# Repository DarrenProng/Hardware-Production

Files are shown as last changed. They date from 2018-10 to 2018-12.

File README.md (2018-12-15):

# TEA5767 FM Radio Receiver Module
## Created by: Darren Prong at Humber College Technical Laboratories
## CENG 317 Instructor: Kristian Medri

## Table of Contents
1. [Introduction](#introduction)

2. [Specifications](#specifications)

3. [Design Files](#design-files)

4. [Assembly](#assembly)

5. [Test Code](#test-code)

### Introduction
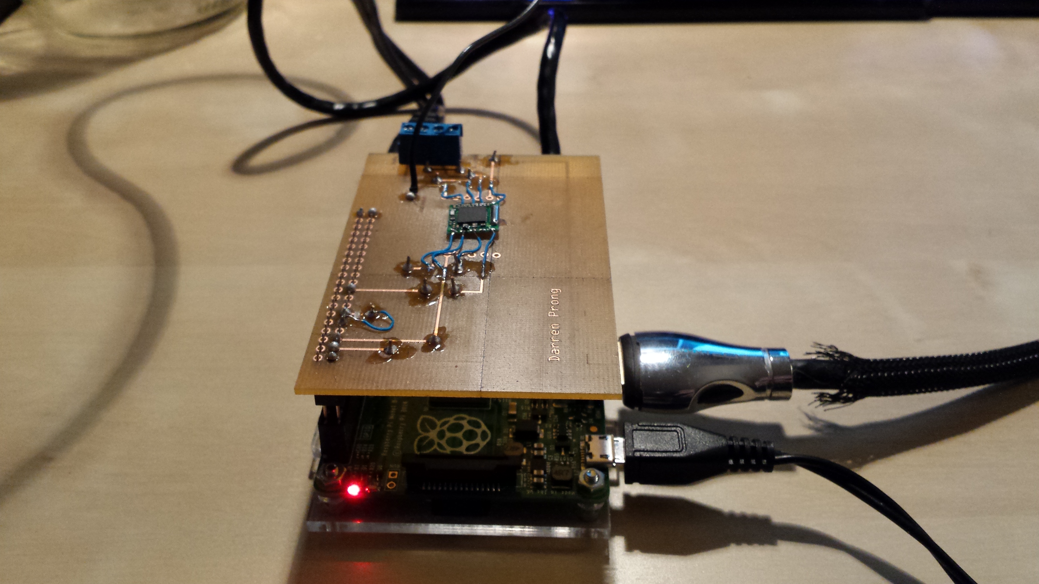
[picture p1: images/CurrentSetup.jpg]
Image of Prototype


This list will allow you to complete a working FM Radio Receiver using the Raspberry PI 3b+ in conjunction with a TEA5767 I2C device.

Ill start by listing the required components, where to buy them, how to design then assemble those components, then finalize with testing the device in an appropriate enviroment.

This project was completed over a 15-week semester, however with these steps, a working prototype could be completed in a week from purchasing components to hearing music on the receiver.

### Specifications
Heres a list of all parts needed to complete this project.

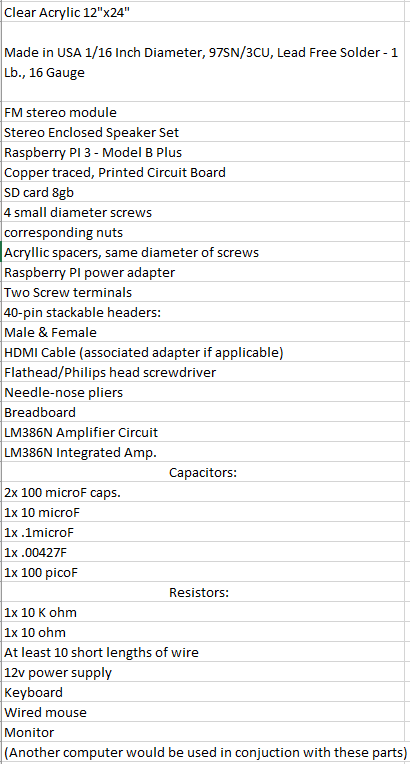
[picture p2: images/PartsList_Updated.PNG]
Image of Parts


Youre budget will vary from mine, as I had a number of components and tools and access to a prototyping lab which greatly decreased my overhead costs. 
I also had to buy additional components that were not originally on the budget or parts list files that I have uploaded HERE on my repository.
As well, my major mistake of frying a Raspberry PI (which could set you back another $50.00) wasn't included in the budget.
The amplifier originally was planned to be the Class-D amp supplied by buyapi.ca, however I had to put togther the LM386 due to time contraints. However, looking back, this would be a better option; thats why I left it on the final parts list.
My total budget by the end of the project was $122.68CAD.
I had intitially proposed a $108 total budget.

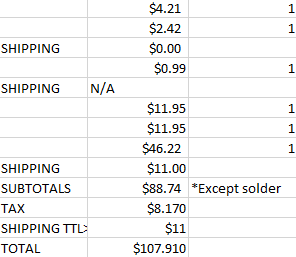
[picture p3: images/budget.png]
Image of Budget


Here is the updated budget
These are the costs to be expected, at least at a minimum.
This was the first attempt at wrangling up some of these cheap sensors.
I went for the cheapest option, and they never arrived.

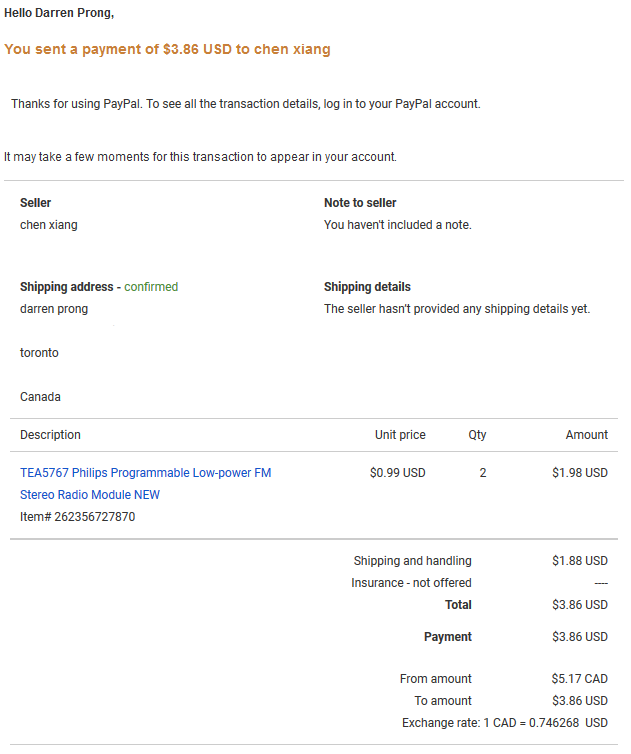
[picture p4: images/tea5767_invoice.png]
Image of Invoice1


Therefore, go for the one that works, and is quick. I bought the back up at oddwires.com for $15.25 USD:

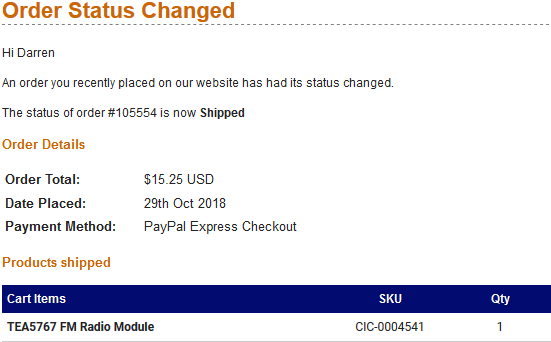
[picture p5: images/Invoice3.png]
Image of Invoice3


The Pi 3B+ is also my choice for which version to go with. 

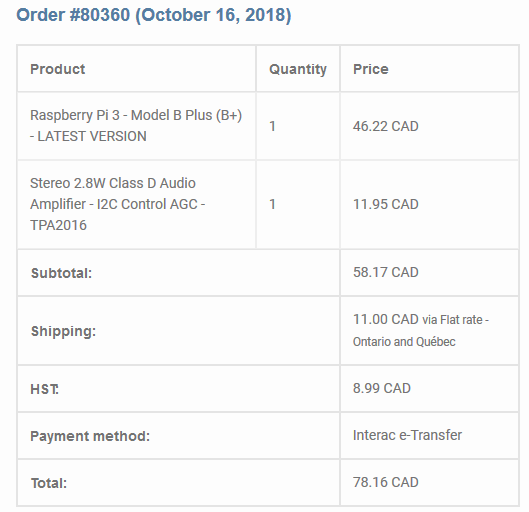
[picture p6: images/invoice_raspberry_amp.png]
Image of Invoice2


Its the same price as the other Pi's but if you already have the associated pieces for assembly, no need to order a whole parts
kit.

Again, these prices are location dependent, as your geographical situation could greatly increase shipping costs or parts availablity. 
As well, in our prototyping lab, we have access to a $20,000 laser cutter, a lot of spare components and tools, the expertise of professionals, and a great deal more time.

### Design Files
Designing this next two major parts will require some trial and error if you haven't used these programs before. Also, if you've ordered your parts and awaiting the sensor in the mail, this can be done in the interim.
To design the device PCB I used the freeware "Fritzing" (which is in BETA at the time of this publication.) 

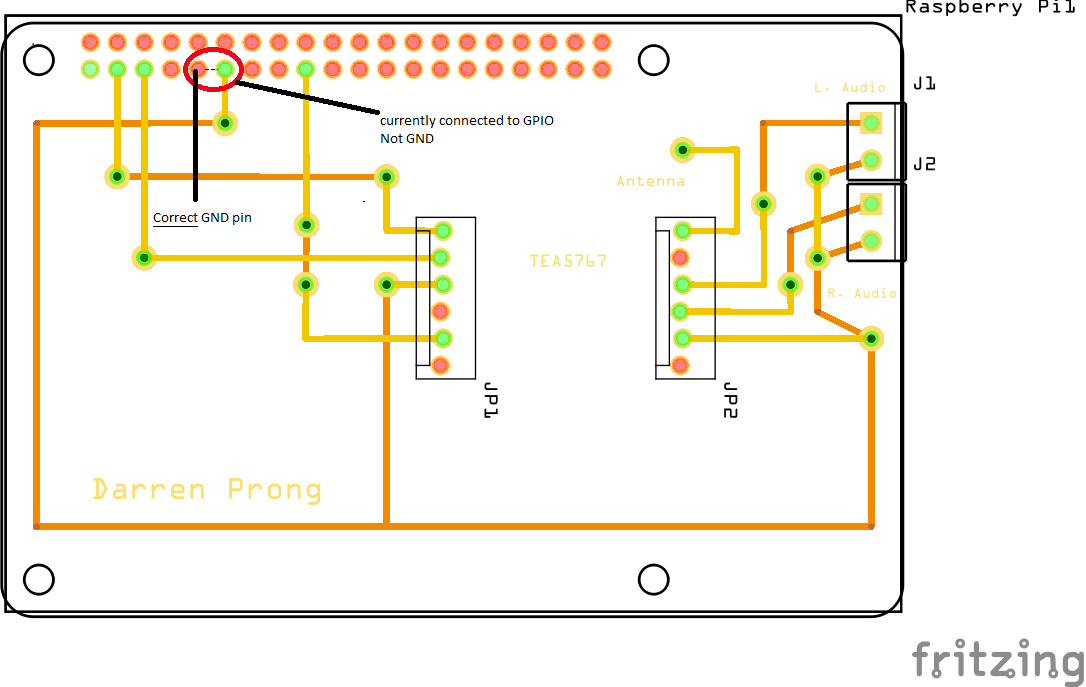
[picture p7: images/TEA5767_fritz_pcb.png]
Image of Fritzing


This files could still use some tweaking, and maybe some personal customization; however, this is the simplest design I could create and good for a beginner to learn the basics.

And for the enclosure, CorelDRAW was used on a free 15-day trial as well as access to the program in our lab.
The enclosure on CorelDRAW:

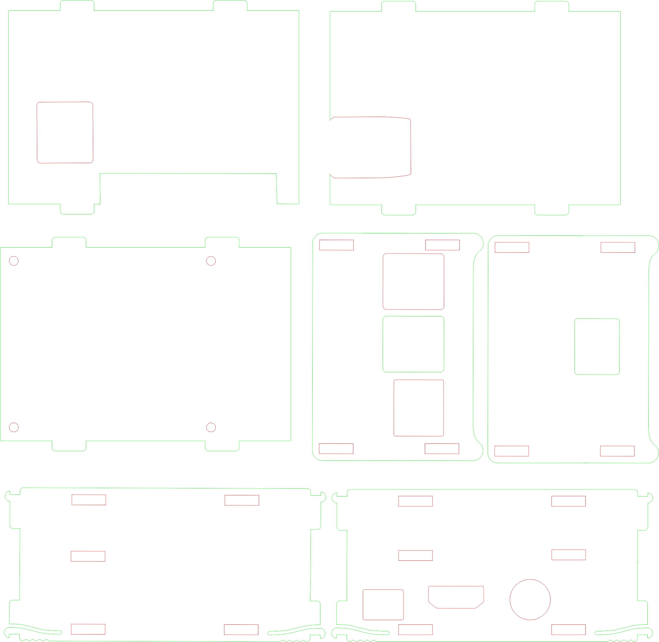
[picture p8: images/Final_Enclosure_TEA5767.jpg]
Image of Enclosure


After these are designed, you can send the fritzing file away to be printed.
The enclosure was printed a few times, with minor changes for each new job. Its still not a perfect fit, but the file you have here [Enclosure](https://raw.githubusercontent.com/DarrenProng/Hardware-Production/master/Final_Enclosure_TEA5767.cdr) will work but the fit is tight, and the middle plate is under pressure from the USB ports pressing from underneath causing it to bend slightly. 

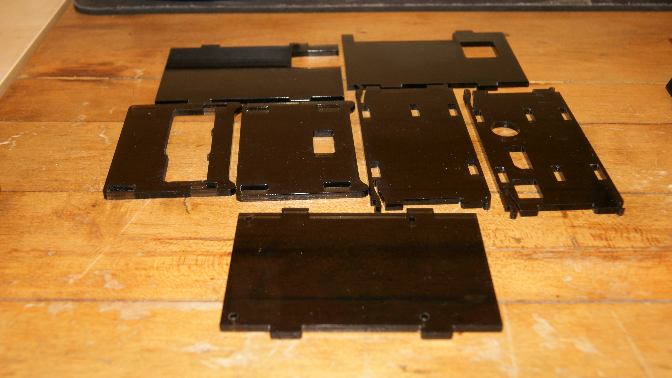
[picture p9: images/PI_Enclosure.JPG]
Image of Pieces

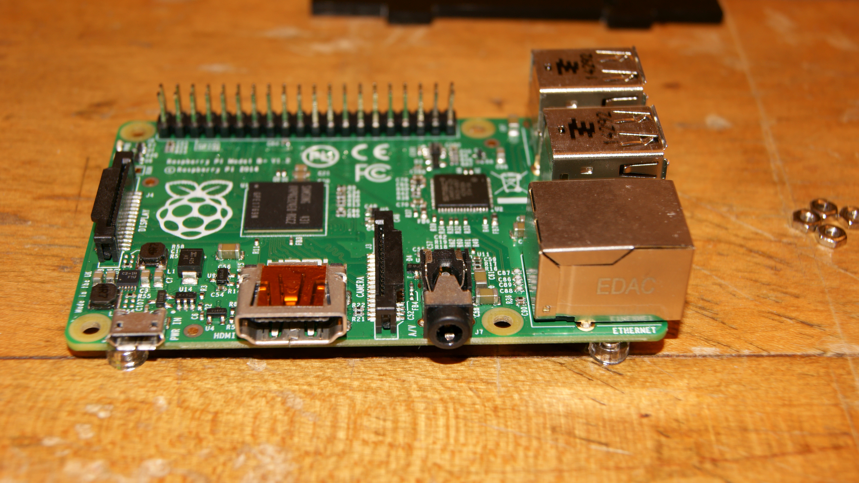
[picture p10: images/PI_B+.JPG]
Image of BarePi

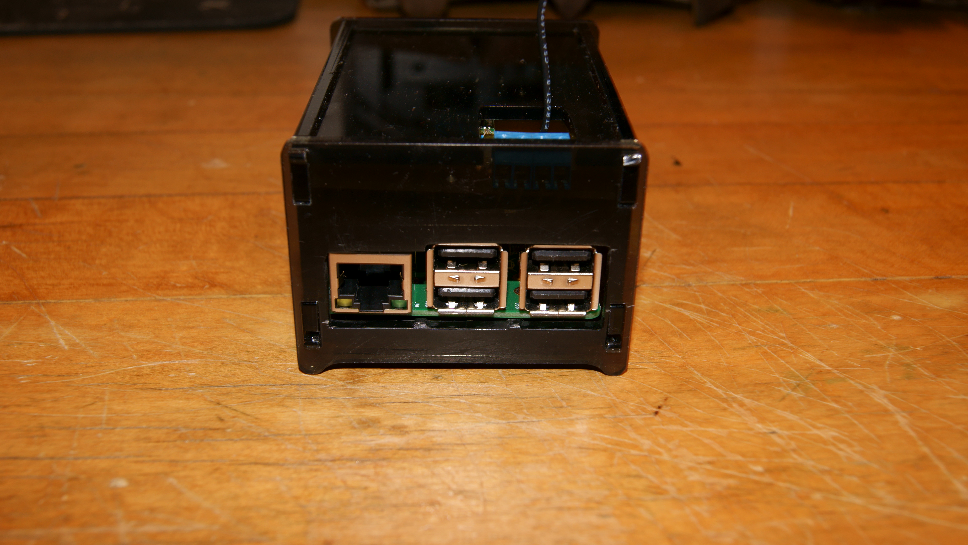
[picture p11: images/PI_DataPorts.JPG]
Image of PiPorts

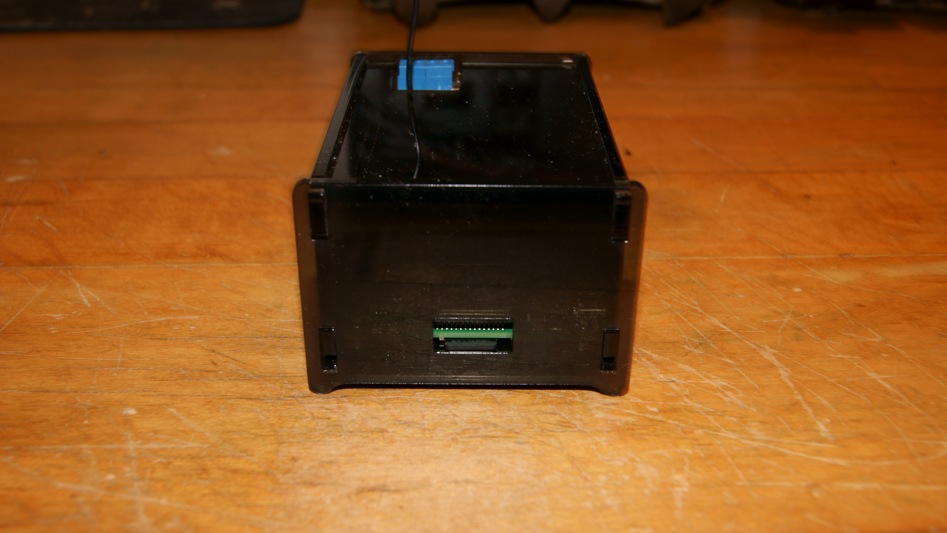
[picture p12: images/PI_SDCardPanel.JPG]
Image of PI_SDCardPanel


I had to remove the I/O spacing bars, and file down the cutouts for my design, however the design .cdr file included in 
this repository, won't have this missalignment.

### Assembly
Once the parts are in hand, the design files printed and assembled, Heres what you should have in hand:
...

Start by attaching the the sensor to the PCB, I used hotglue.

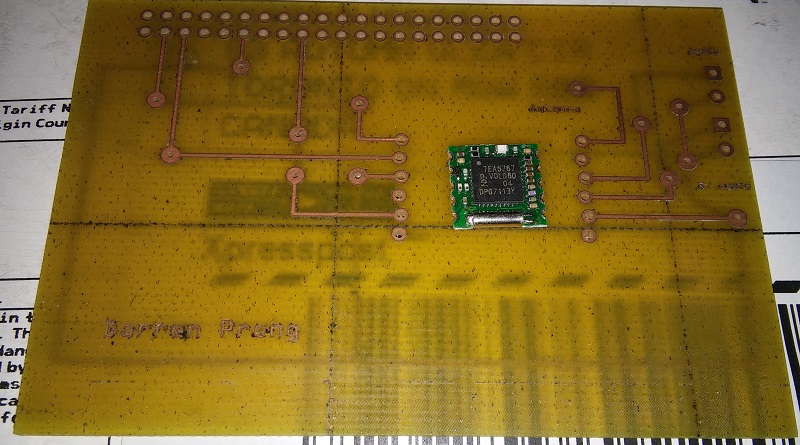
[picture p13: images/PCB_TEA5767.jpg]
Image of TEA5767


Next step will be to solder a jumper wire from each terminal on the sensor to the corresponding trace on the PCB.

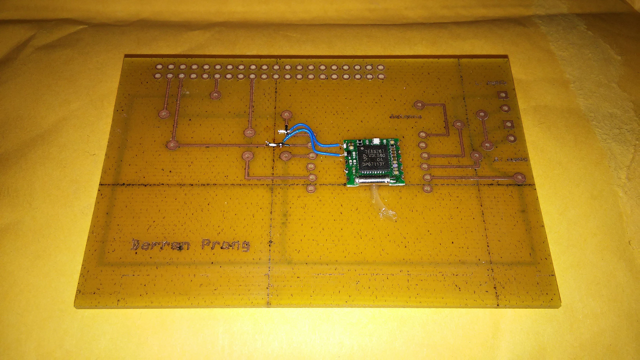
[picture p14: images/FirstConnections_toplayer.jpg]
Image of Connection


Next will be to solder the via's. I recommend that you take a small amount of 20gauge wire(1cm in length) strip only one end and then insert into all the via's. This will hold it inside the via briefly while you solder the flip side. Solder the entire side with exposed wire first, then flip, remove the insulation, and solder that side for each via.

Double check the shape of each via and how the solder "flows" from the wire onto the copper pad. This ensures a solid connection. It should appear like a sloping hill, or a "Hershey Kiss".

Next, the 40-pin stackable header, along with the two screw terminals to be used with your speakers.

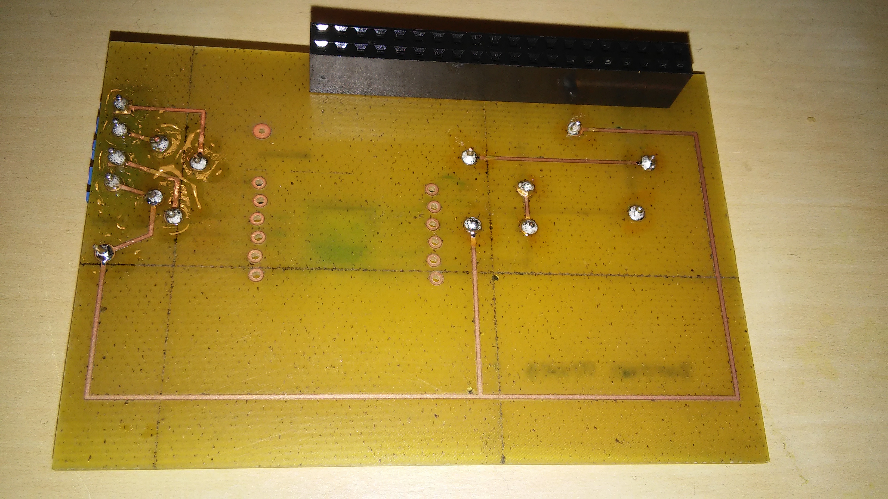
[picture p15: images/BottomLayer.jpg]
Image of Bottom


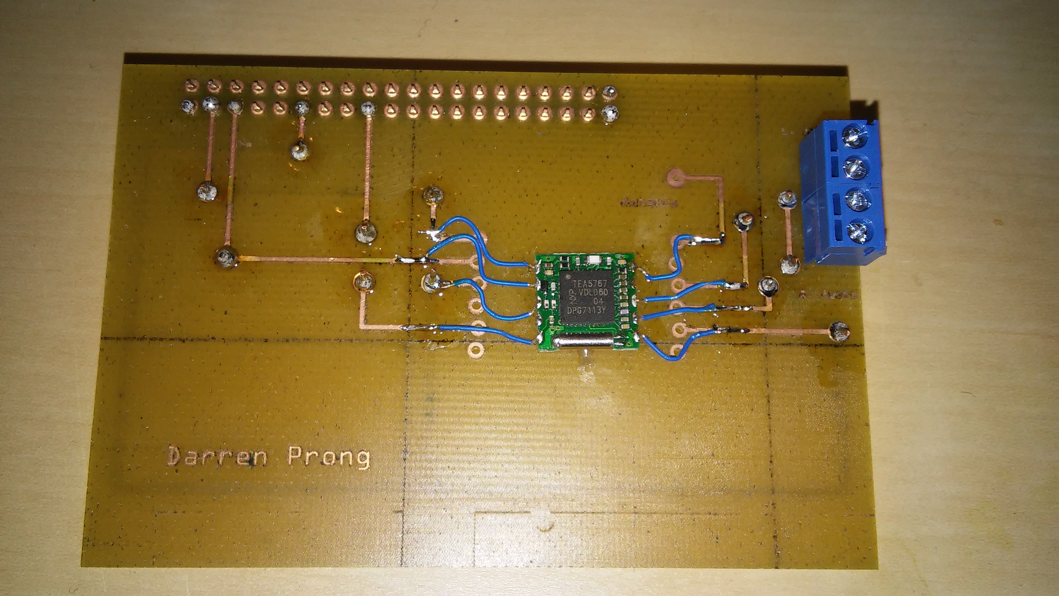
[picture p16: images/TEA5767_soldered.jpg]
Image of Top


Soldering all 40pins isn't necessary, I only soldered the pins I was using, and two on the far end of the header.

I also left my male 40-pin header plugged in, so I didnt lose it. However, you'll notice it doesn't rest flush up agaisnt the the female header. This could potentially damage both headers as well as the device. 

Best practice would be to disconnect from the PI each time your completed testing. 

You can now solder on a length of wire (up to you how long) to act as the antenna. Solder this in a similar way as you did with the via's.

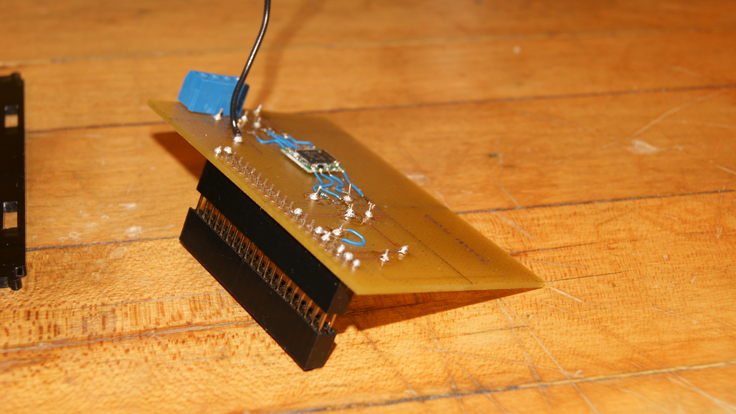
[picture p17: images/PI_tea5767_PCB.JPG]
Image of PI


PS. Ignore the jumper wire from the ground trace to pin 5. This was where I made a critical error in my fritzing design.
The updated .fzz has fixed this issue.

 Next and final step for assembly, attach your PI to the base plate of the acryllic enclosure with the ordered hardware and printed standoffs. 
 
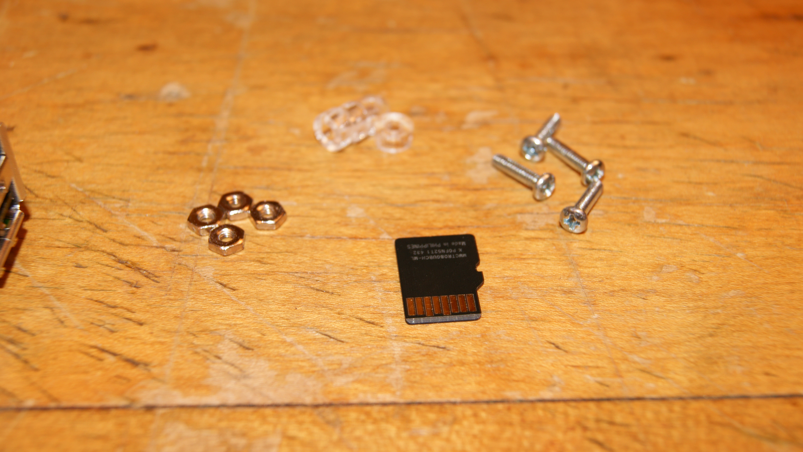
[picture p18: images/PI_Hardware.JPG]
Image of Hardware
 
 
 Do one hole at a time. Keep the device firmly planted on a flat surface. (hang over on hole on the edge of a table for example) place the standoffs in between the board and the base plate. Line up the holes, and insert a screw. While keeping the screw in place with your small philips head screw driver, place a nut on the threads with the needle nose pliers. The pliers are to be help still, just keep the nut from turning. Use the screwdriver to tighten, just until enough threads are engaged to hold the screw in place. Repeat for all four holes. Final step is to tighten down snugly, not firmly, on all four screws.
 
You can now attach all parts of the enclosure to the base, and plug in the PCB/device combo into the GPIO pins.

The final product:

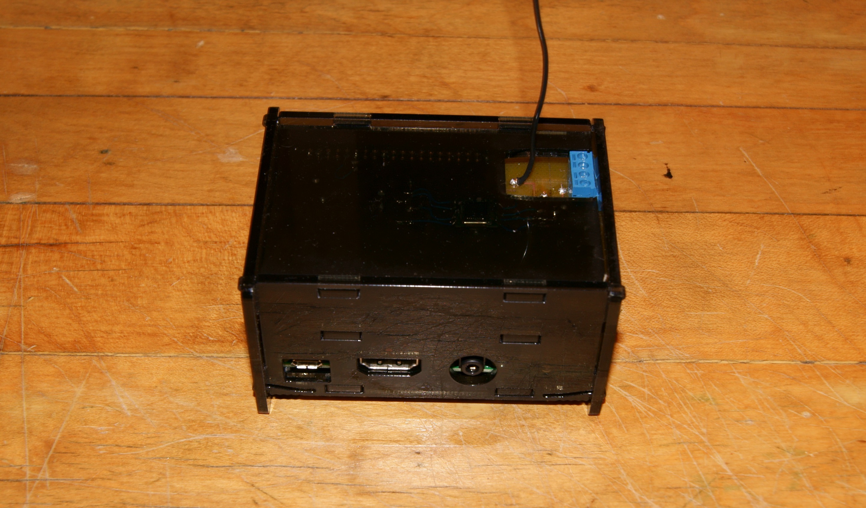
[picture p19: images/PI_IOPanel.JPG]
Image of Case


### Test Code

The first step in making sure your PI will be able to play music will be its ability to first boot up, then to enable I2C devices, then to detect that the PI can recognize the sensor.

First, enable the I2C bus on your PI.

Go to:
/boot/config.txt

add these lines to the bottom of the file:
```
dtparam=i2c_arm=on
dtparam=spi=on
dtparam=i2s=on
dtparam=i2c1=on
```

Next, type:	
```
gpio -v
```
	
 Make sure you have WiringPi libraries installed
	If no version is available, please try the following commands: 	

 ```
sudo apt-get install upgrade
sudo apt-get install update
sudo apt-get install i2c-tools
sudo apt-get install wiringpi
sudo apt-get install smbus
```
Now we need to edit the file
```
sudo nano /etc/modules
```

Add these lines here: 

```
i2c-bcm2708
```

and here:

```
i2c-dev

```

at the bottom of the file, and remember to write to file before exiting.

Also, we need to enable i2c at boot. So now we run the:

```
sudo raspi-config
```
Next, navigate through the first menu 

<!-- answer from: anonymoose March 9th 2017 Source. https://raspberrypi.stackexchange.com/questions/63076/advanced-options-i2c-not-showing -->

found this at raspberrypi.stackexchange.com//questions/63076/advanced-options-i2c-not-showing. This shows step by step what to do in a 12 second .gif.

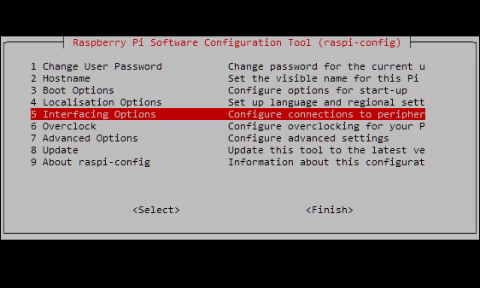
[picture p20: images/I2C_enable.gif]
Image of EnableConfig


After the I2C bus has been enabled, the /modules file edited and saved, any missing libraries installed;
open a new file for editing in VIM. Name the file radio.c. 
```
radio.c

#include <wiringPi.h>

#include <wiringPiI2C.h>

#include <stdio.h>

#include <stdlib.h>

int main( int argc, char *argv[]) {

  printf ("RPi - tea5767 Philips FM Tuner v0.3 \n") ;

  unsigned char radio[5] = {0};

  int fd;

  int dID = 0x60; // i2c Channel the device is on

  unsigned char frequencyH = 0;

  unsigned char frequencyL = 0;

  unsigned int frequencyB;

  double frequency = strtod(argv[1],NULL);

  frequencyB=4*(frequency*1000000+225000)/32768; //calculating PLL word

  frequencyH=frequencyB>>8;

  frequencyL=frequencyB&0XFF;

  printf ("Frequency = "); printf("%f",frequency);

  printf("\n"); // data to be sent

  radio[0]=frequencyH; //FREQUENCY H

  radio[1]=frequencyL; //FREQUENCY L

  radio[2]=0xB0; //3 byte (0xB0): high side LO injection is on,.

  radio[3]=0x10; //4 byte (0x10) : Xtal is 32.768 kHz

  radio[4]=0x00; //5 byte0x00)

 if((fd=wiringPiI2CSetup(dID))<0){

 printf("error opening i2c channel\n\r");

 }

write (fd, (unsigned int)radio, 5) ;

return 0;

}
```
Once saved as radio.c, 

```
gcc -o radio radio.c -lwiringPi
```

Credit for the above code goes to "halfluck" on the Raspberry Pi forums.
```
https://www.raspberrypi.org/forums/viewtopic.php?t=53680&p=419429

```

The command to be run here is: 
```
sudo i2cdetect -y 1
```

This will display all open addresses and will display a hexadecimal value representing the module. We need 0x60. 

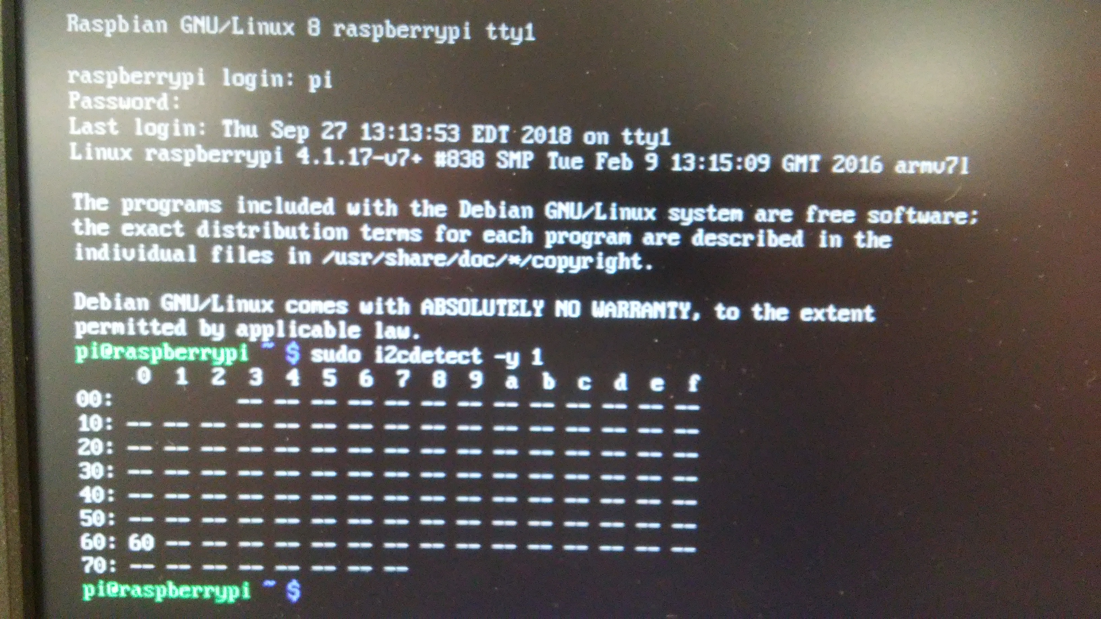
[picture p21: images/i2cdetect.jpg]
Image of Detecting


If you see any other address, there may be some other issue regarding your device; I would look into this guide:

https://raspberrypi.stackexchange.com/questions/76072/inconsistent-i2c-bus-address-listings-causing-sensor-reading-issues

or many others like it across the web. 

If everything is looking good, you can continue.
Now we're ready to play music but most likely you haven't plugged in your speakers. I had two 4.3ohm desktop speakers
from an old set I found at my house. One was broken and couldn't play anything, and the other was working just fine.
Test them first in your amplifier. Supply a low power frequency to the input of the LM386, shown here:

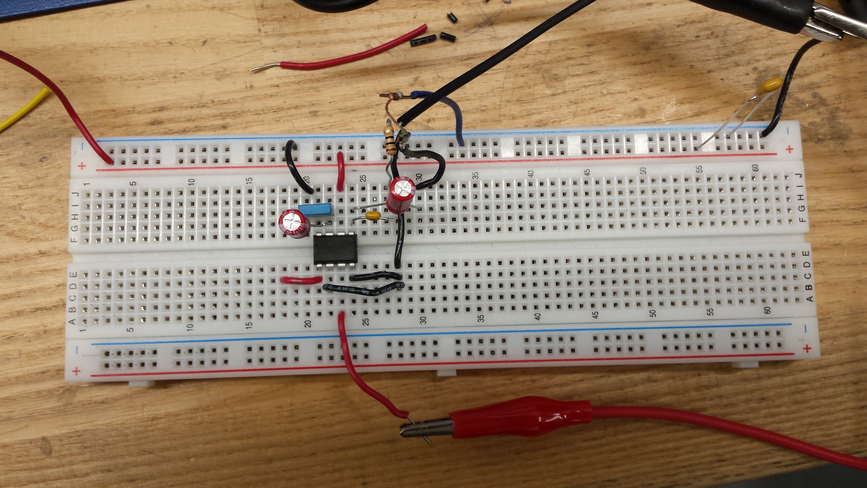
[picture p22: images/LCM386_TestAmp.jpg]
Image of Amplifier


Heres it breadboarded virtually using fritzing:

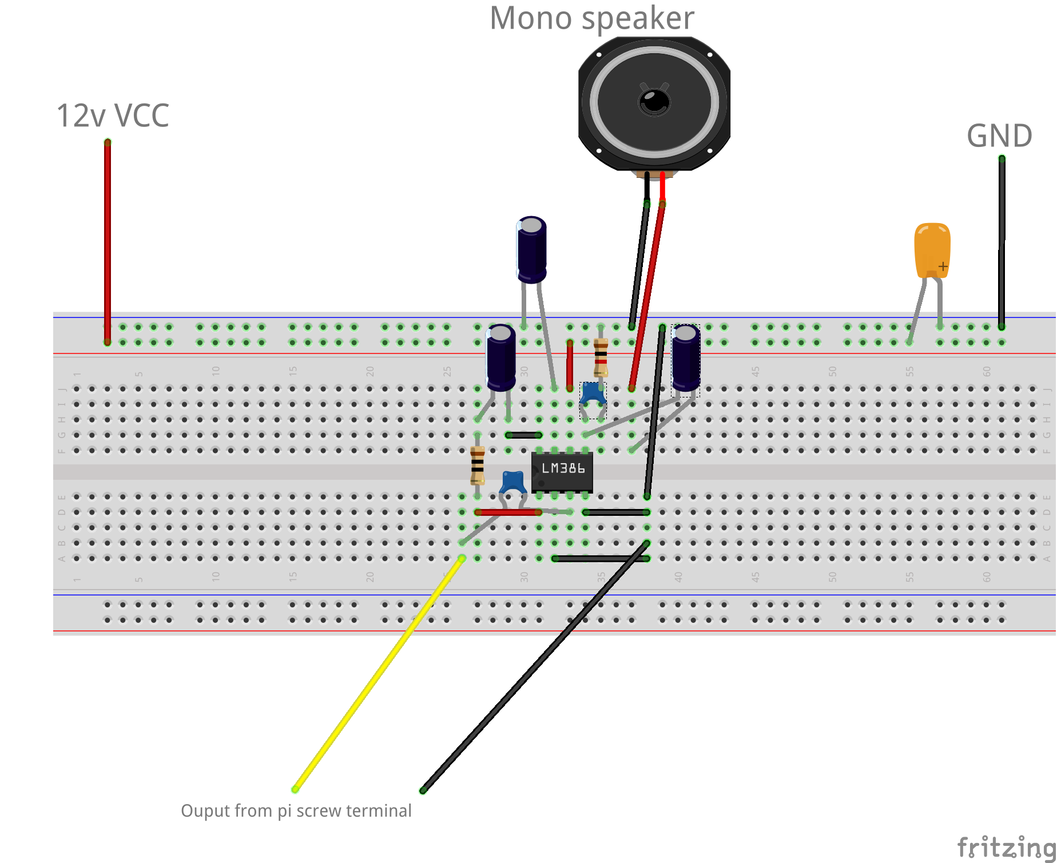
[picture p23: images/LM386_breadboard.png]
Image of Amplifier


Once you test has gone through with your speaker, test it out while running the PI hooked up to the amp.
```
sudo ./radio xx.x //your radio station frequency of choice
```
It should come out sounding a little something like this:

https://www.youtube.com/embed/gSB8UnMIgSc

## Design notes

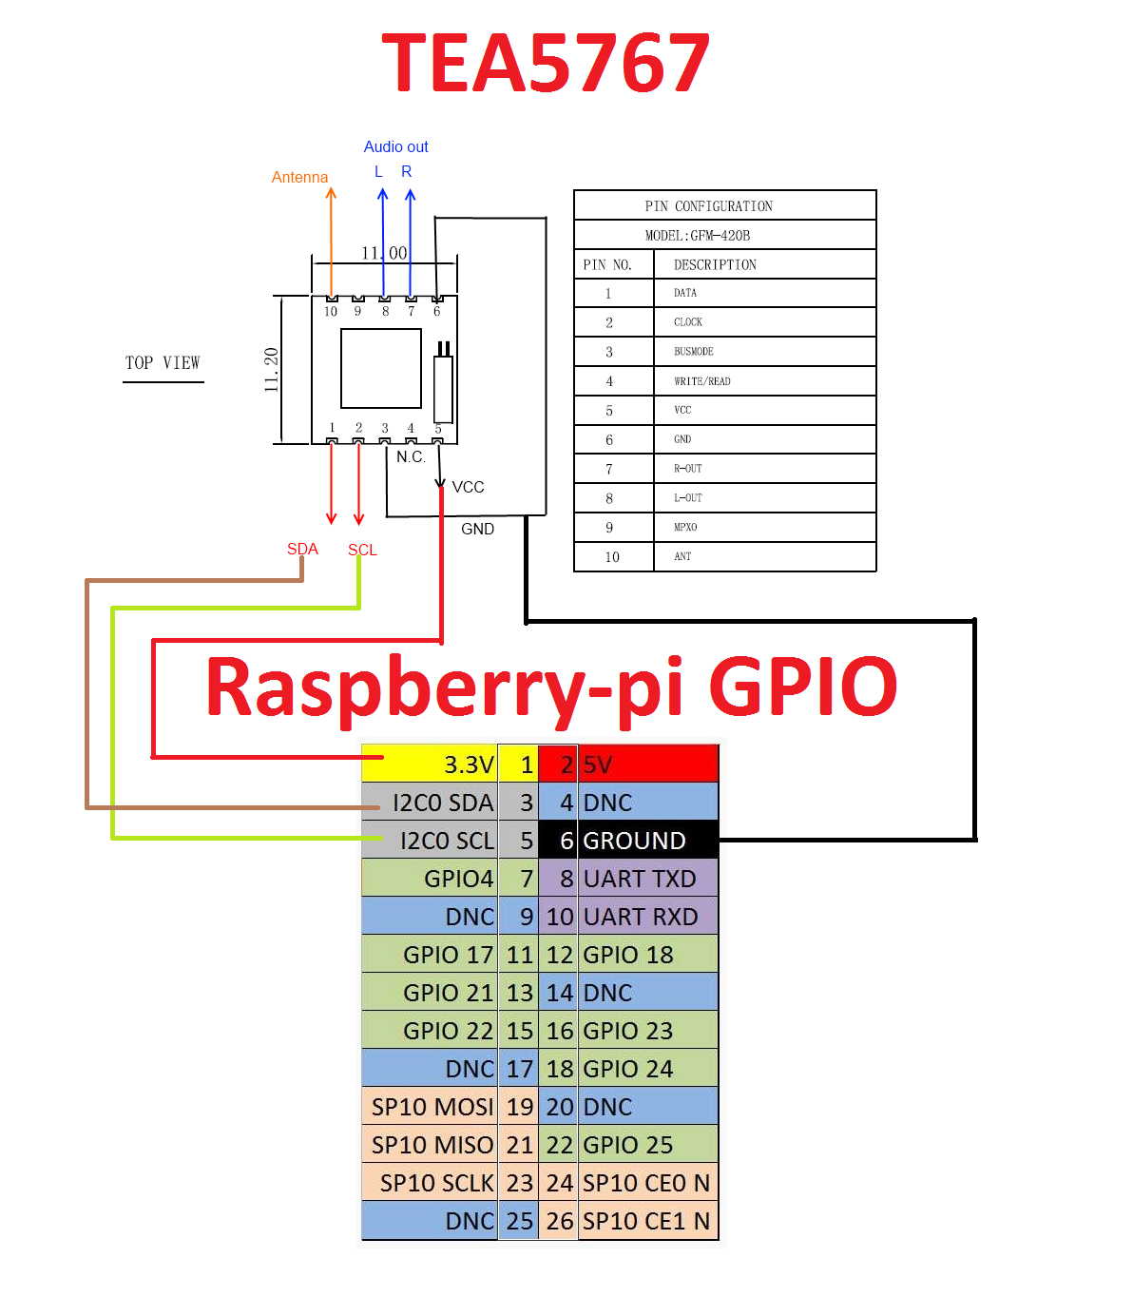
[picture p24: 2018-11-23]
images/pinout_TEA5767module.png

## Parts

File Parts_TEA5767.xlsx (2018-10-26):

Parts for TEA5767
by: Darren Prong
Description | Source | Part # | US$ Unit Cost | CAD$ Unit Cost | Number of units | US$ Subtotal | CAD$ Subtotal | Link | Comments
Clear Acrylic 12"x24" | School |  |  | ???
Acrylic cutting at a dollar per minute | School |  |  | ???
Made in USA 1/16 Inch Diameter, 97SN/3CU, Lead Free Solder - 1 Lb., 16 Gauge | mscdirect.com | 31780653 |  | $41.84 | 1 |  |  | https://www.mscdirect.com/industrialtools/1-pound-lead-free-solder.html | *maybe free from the school??
Dual-Channel Amplifier Module | dx.com | PAM8403 |  | $4.21 | 1 |  |  | https://www.dx.com/p/pam8403-dual-channel-amplifier-module-blue-216853#.W6qWE_kpBhF
USB Sound card adapter | dx.com | 59039 |  | $2.42 | 1 |  |  | https://www.dx.com/p/5-1-channel-usb-sound-card-adapter-black-59039#.W6qeS_kpBhE
 |  |  | SHIPPING | $0.00
FM stereo module | ebay.com | N/A |  | $0.99 | 1 |  |  | https://www.ebay.com/p/Tea5767-Philips-Programmable-Low-power-FM-Stereo-Radio-Module/1431487119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 | *conditional on quantity available
 |  |  | SHIPPING | N/A
Stereo Enclosed Speaker Set | buyapi.ca | SKU: 1152 |  | $11.95 | 1 |  |  | https://www.buyapi.ca/product/stereo-enclosed-speaker-set-3w-4-ohm/
Stereo 2.8W class D audio Amplifier I2C Control | buyapi.ca | SKU: 104 |  | $11.95 | 1 |  |  | https://www.buyapi.ca/product/stereo-2-8w-class-d-audio-amplifier-i2c-control-agc-tpa2016/
Raspberry PI 3 - Model B Plus | buyapi.ca | SKU:9001 |  | $46.22 | 1 |  |  | https://www.buyapi.ca/product/raspberry-pi-3-model-b-plus/
 |  |  | SHIPPING | $11.00
 |  |  | SUBTOTALS | $88.74 | *Except solder
 |  |  | TAX | $8.170
 |  |  | SHIPPING TTL> | $11
Total for parts from CAD sources |  |  | TOTAL | $107.910
Total for parts from US sources |  |  | TOTAL | N/A

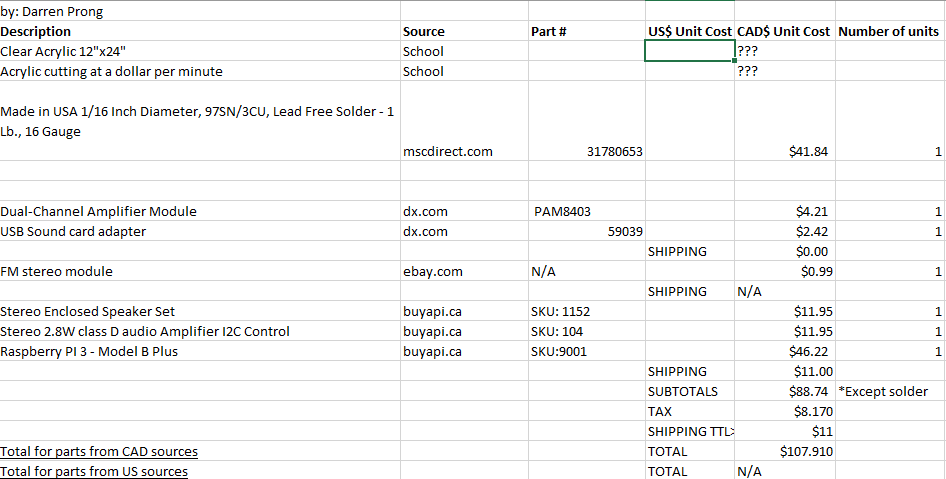
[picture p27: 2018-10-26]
images/PartsList.png

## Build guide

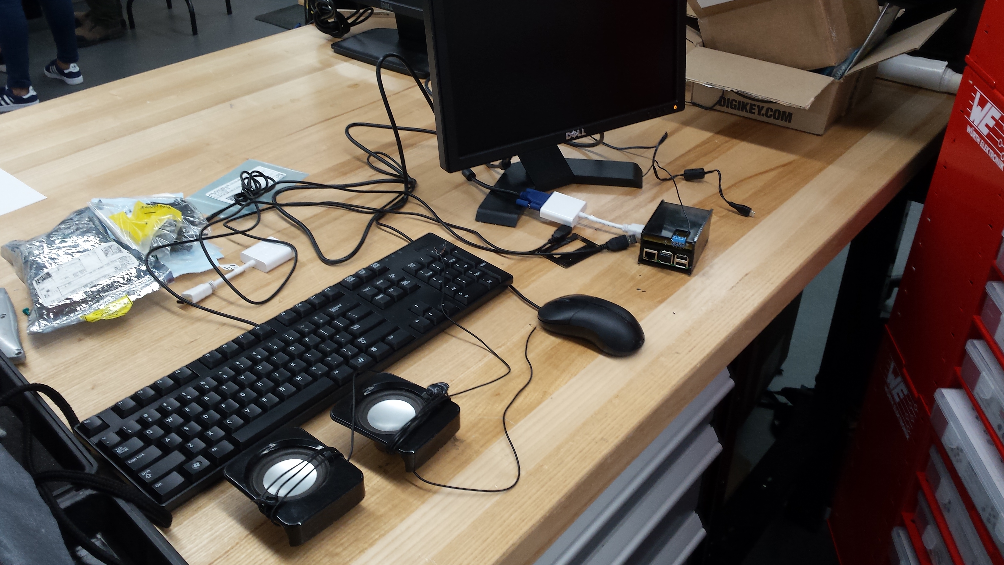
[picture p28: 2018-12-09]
images/workingSetup.jpg

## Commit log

2018-10-03 Budget, Summary, Parts diag, and more.
    [Parts_TEA5767.xlsx]
2018-10-26 updating parts
    updating parts list with images
    [Parts_TEA5767.xlsx]
2018-10-26 Update README.md
    couple more photos
2018-11-01 TEA5767 Fritz
    my PCB diagram and layout
    [TEA5767_fritz.fzz]
2018-11-01 Switching default.html to index.html
2018-11-01 Removing jekyll dependency
    Couldn't get anything working, + wasn't going to get any marks for it
    [TEA5767_fritz.fzz]
2018-11-03 Fritzing Design
    [TEA5767_fritz.fzz]
2018-11-15 missed a bracket
2018-11-29 Some recent prototypes
2018-12-09 Finished Prototype pics + amplifier pics
2018-12-09 publish final enclosure design file
2018-12-11 basic framework
2018-12-11 images, updating fritzing file
    [TEA5767_fritz.fzz]
